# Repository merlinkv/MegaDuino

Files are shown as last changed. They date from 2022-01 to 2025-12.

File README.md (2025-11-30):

<br />This work is licensed under a <a rel="license" href="http://creativecommons.org/licenses/by-nc-sa/4.0/">Creative Commons Attribution-NonCommercial-ShareAlike 4.0 International License</a>.

* If you remix, transform, or build upon the material, you must distribute your contributions under the same license as the original.
* You may not use the material for commercial purposes.
* You must give appropriate credit, provide a link to the license, and indicate if changes were made. You may do so in any reasonable manner, but not in any way that suggests the licensor endorses you or your use.

# ATTENTION

   - This project was made for retro community, individuals or forums, and **NOT FOR COMMERCIAL PURPOSES**.
   - Its commercial sale on eBay, auction sites or shops (online or not) is PROHIBITED.
   - So only retro hardware forums and individual people with non profit intentions can build this project.

# Exception

  - If you wish to sell small quantities of this interface in a physical or online store, you must first contact me to request permission. The ban on selling it on eBay or auction sites remains in effect.

# Note

I take no responsibiltiy for any damage to any equipment that results from the use of this board.

USE AT YOUR OWN RISK!

# MegaDuino

An improved versión of the initial project started by me on September 2019.

MegaDuino is an evolution of other projects like TZXDuino and CASduino but it's based on the Arduino Mega 2560 Pro Embed board.

MegaDuino works with my **MegaDuino Firmware** version, a modification of the MaxDuino firmware specially developed for Arduino Mega 2560 family boards,
OLED 128x64 1.3" (64 rows) & LCD 20x4 screens, it also add an extra button for Reset or future purpouses. MaxDuino firmware from rcmolina can be used as well.

MegaDuino it's a digital cassette tape player that allows the load of games and applications on retro computers, mainly 8-bit computers such as the
ZX Spectrum, Amstrad CPC and others.

A special thanks to Alfredo (acf76es), without his help this update would not have been possible.

Original firmware based on developments by Andrew Beer, Duncan Edwards, rcmolina and others.

**MegaDuino** has been tested on **ZX Spectrum**, **Amstrad CPC**, **MSX**, **Oric Atmos**, **Dragon**, **Tandy Coco**, **Acorn Electron**, **BBC-Micro**, **ZX80** & **ZX81** computers.

# Board revisions and notes

* **30-11-2025 - MegaDuino 8.0**
  - Revised amplifier circuit
  - Some minor changes
  - [Interactive BOM MegaDuino 8.0](https://htmlpreview.github.io/?https://github.com/merlinkv/MegaDuino/blob/master/MegaDuino_8_0.html)

* **12-01-2025 - MegaDuino 5.5**
  - Added External Power Jack
  - Supressed Remote2 connector
  
* **12-08-2024 - MegaDuino 5.0 - Final**
  - Fixed some routing mistakes.
  - Board is fully working now

* **07-01-2024 - MegaDuino 5.0b (Beta - Not Tested)**
  - Although there are many versions of digital players for our retro equipments. It has encouraged me to do a new review of my **MegaDuino** project, with the idea of eliminating things that have proven to be unnecessary, giving it a much smaller format (note that it is not a mini or nano) and greater overall quality of the gadget.
  - Now the board use a mSD connector
  - Circuit of the mSD made with the help of @cacharreo (from VDR Forum), thanks my friend!
  - This Beta version is not tested at the moment. If you want to build one, use the v4.7.

* **01-01-2022 - MegaDuino 4.7**
  - In most cases is best to use the MegaDuino with the amplifier OFF.
  - Removed external power jack & led.
  - A 4-row piano switch was added to allow selection of remote and audio cable type (3.5mm jacks).
  - Added footprint to add one ICSP connector (optional) to allow use the Mega 2560 as master/slave board without opening the case.
  - Audio GAIN & FILTERS

* **05-10-2020 - MegaDuino PM 1.3**
  - All capacitors & resistors are SMD
  - Added Buzzer circuitry to allow listening the loading sounds directly from MegaDuino. Can be activated or deactivated.
  - Added 3mm leds for External Power, USB Power, Amplifier ON, Amplifier OFF & Buzzer ON/OFF
  - Amplifier & Buzzer gain can be selected (Amplifier 20, 50 & 200 - Buzzer 20 & 50) by jumpers
  - Two Remote connectors 2.5mm & 3.5mm to allow all connection possibilities
  - Removed ICSP pins

* **16-05-2020 - MegaDuino 2.9**
  - Reworked amplifier schema and added a DPDT slide switch to completely separate signal when the amplifier is ON or OFF.
  - Reworked connections of the Audio OUT jack to allow use of stereo or mono cables without need to modify them. Also eliminates undesired signals.
  - Removed extra 5v & 3.3v pins
  - ICSP pins moved to a better position to allow program the Mega 2560 or use master/slave boards without opening the case.

* **11-04-2020 - MegaDuino 2.8**
  - Jumpers added to allow selection of signal gain. Now it's possible to select between 50 and 200.

# Links:

* https://www.va-de-retro.com/foros/viewtopic.php?p=189490#p189490

# Images

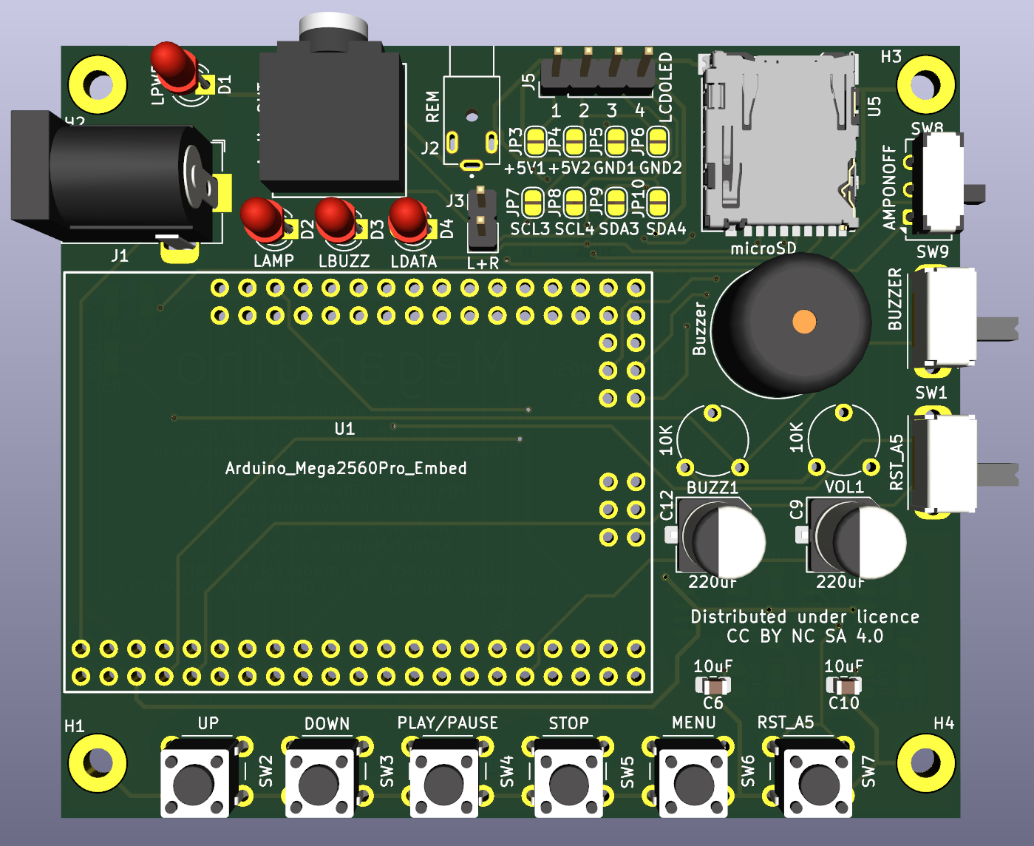
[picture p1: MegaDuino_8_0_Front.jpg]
Version 8.0 Front


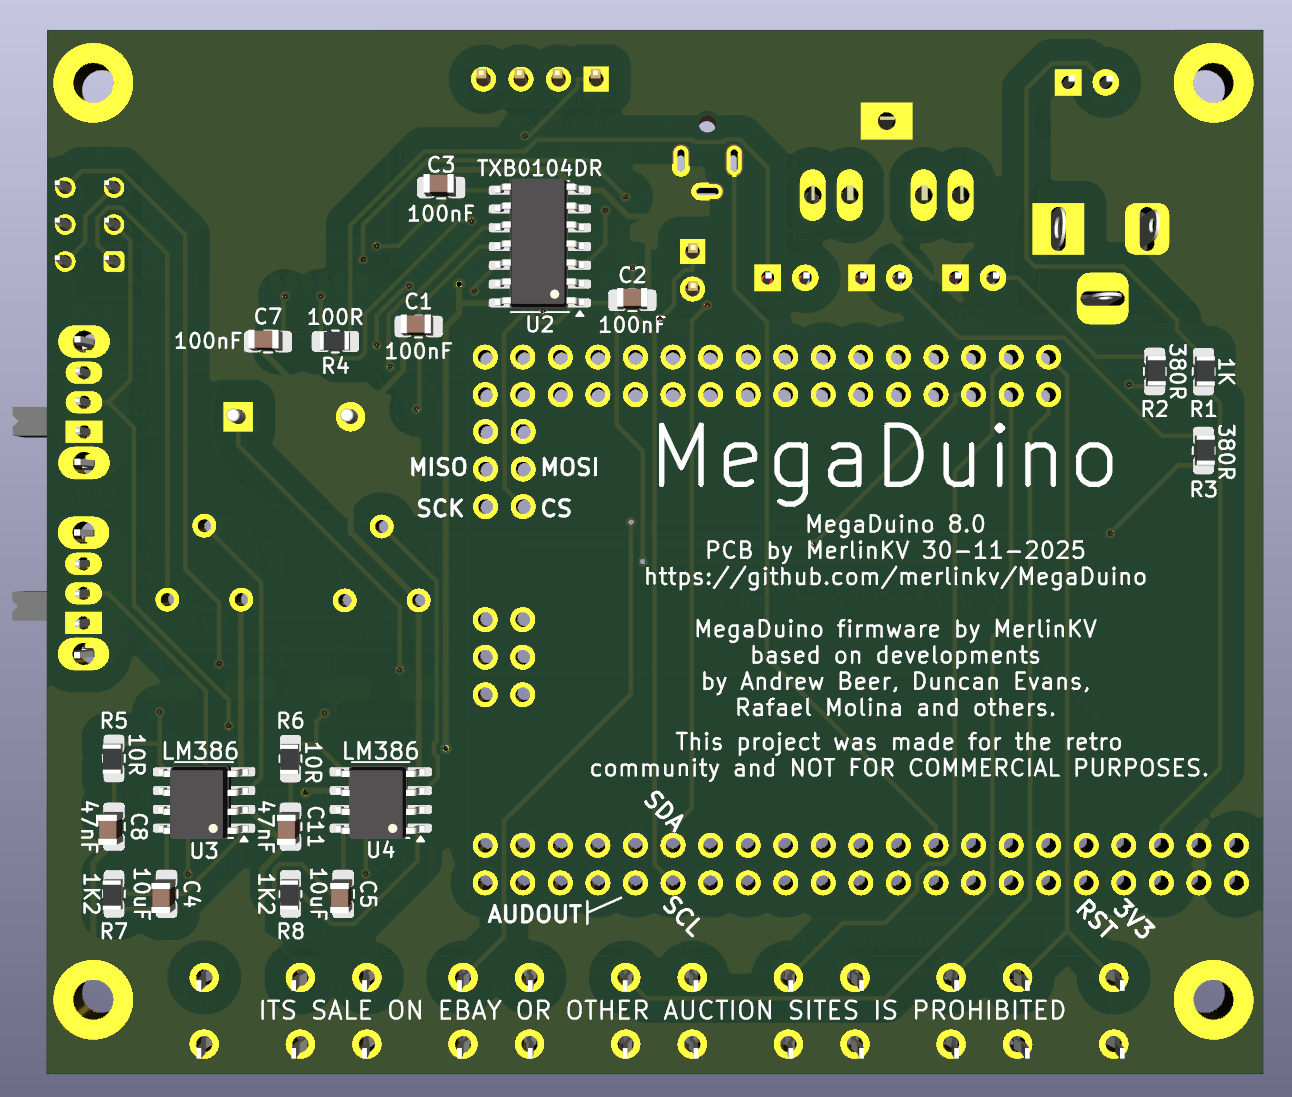
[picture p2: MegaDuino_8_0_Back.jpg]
Version 8.0 Back


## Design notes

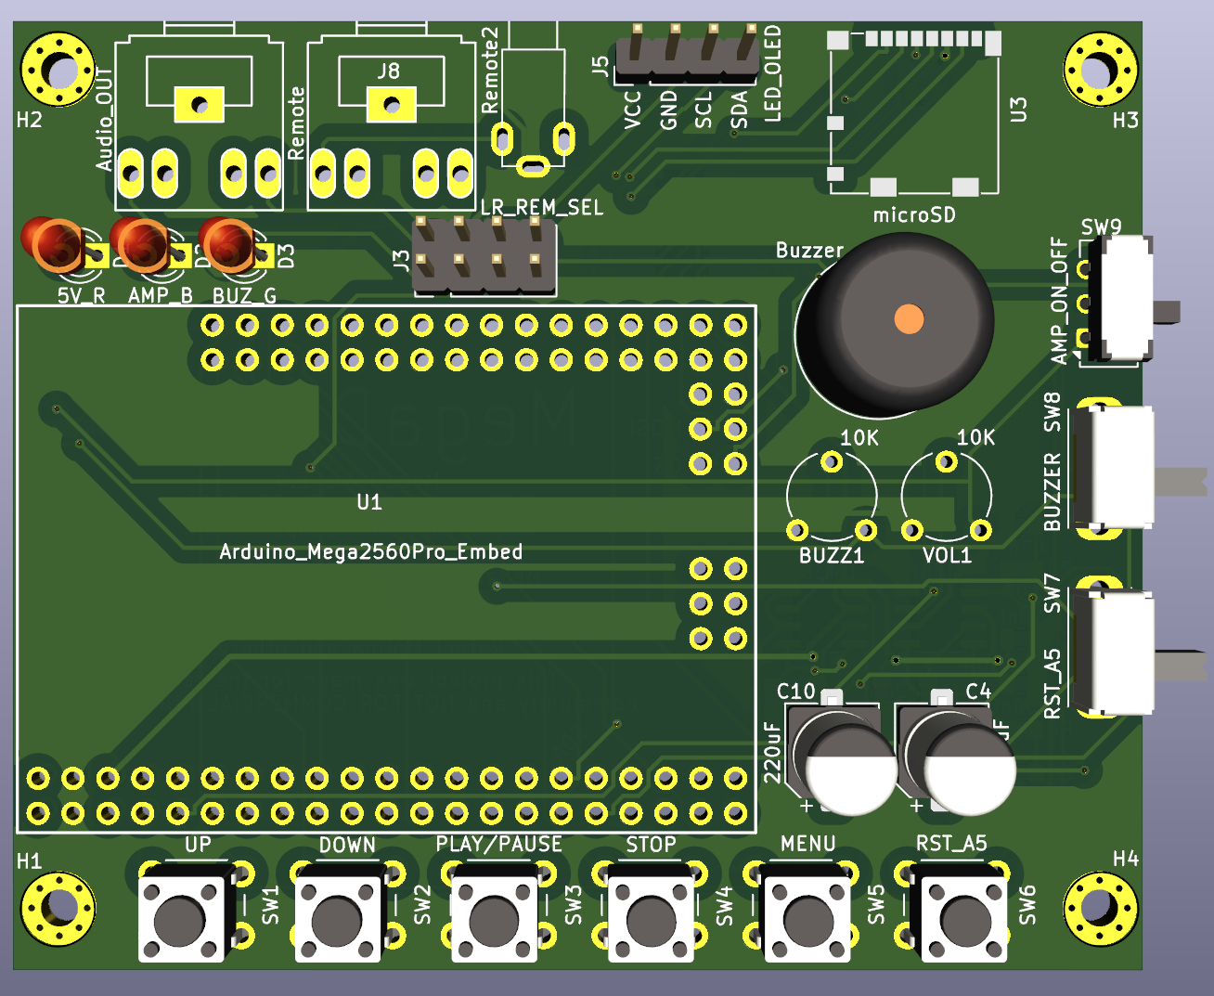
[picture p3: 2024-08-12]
MegaDuino_5/MegaDuino_5_Front.jpg

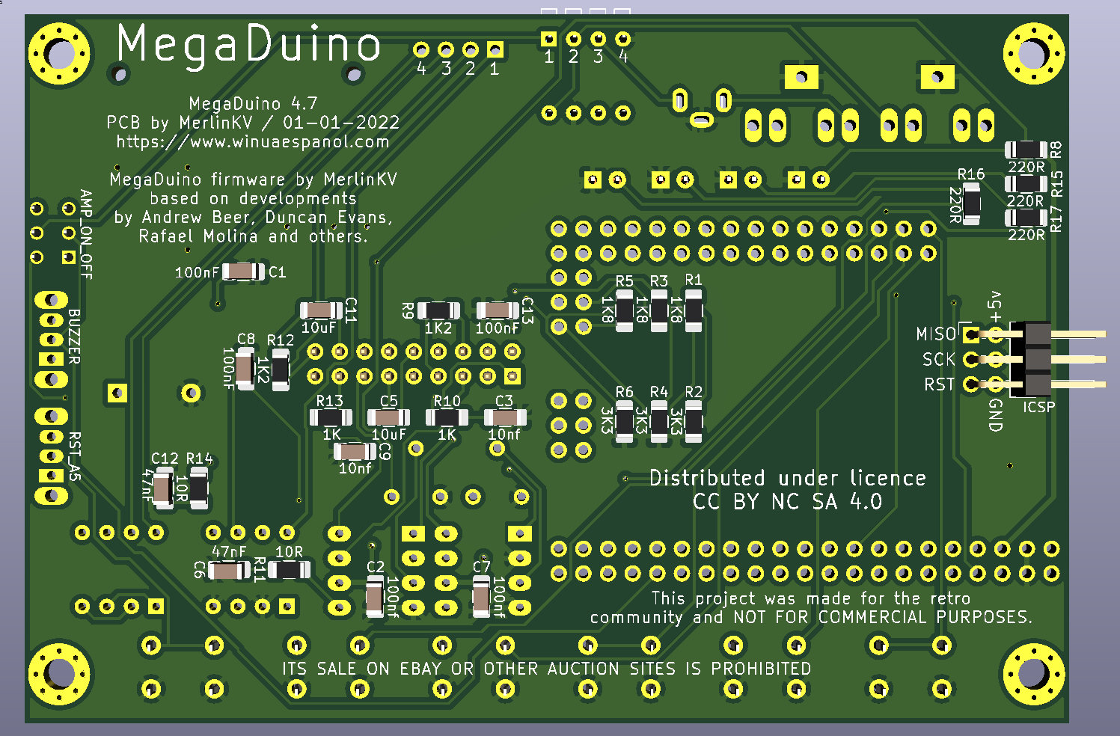
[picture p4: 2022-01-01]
MegaDuino_4_7/MegaDuino_4_7_Back.jpg

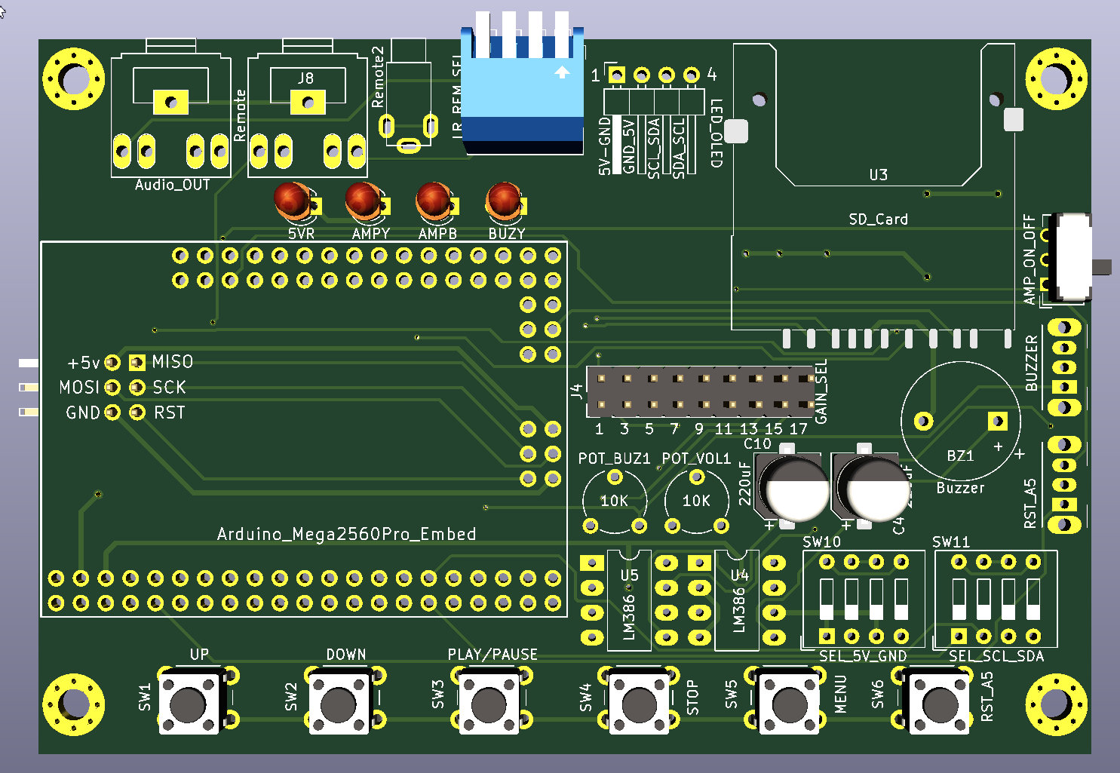
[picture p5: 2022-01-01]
MegaDuino_4_7/MegaDuino_4_7_Front.jpg

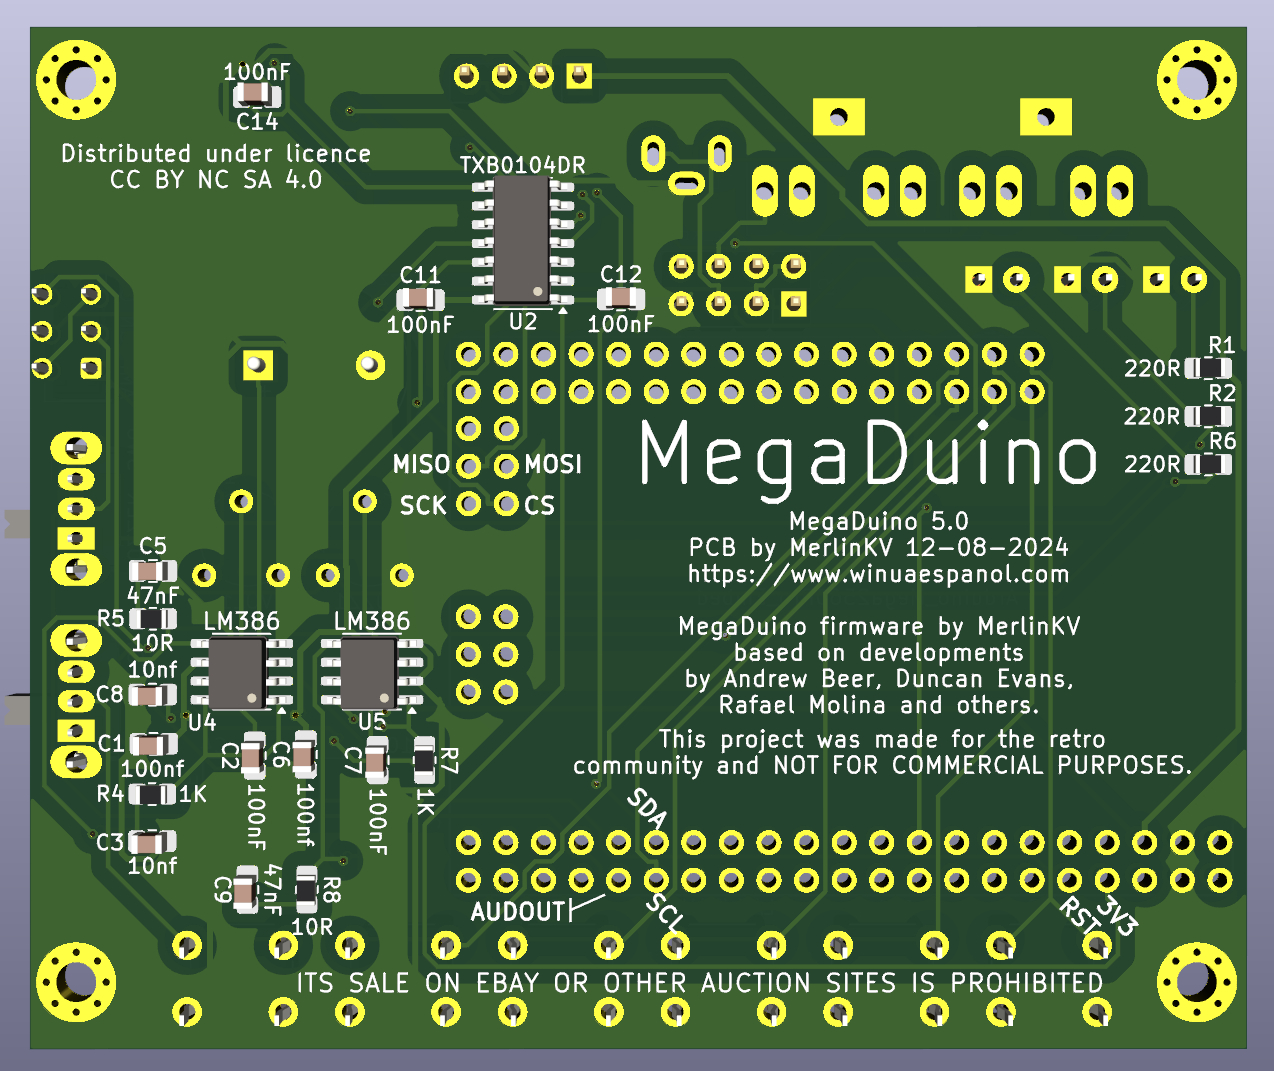
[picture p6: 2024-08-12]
MegaDuino_5/MegaDuino_5_Back.jpg

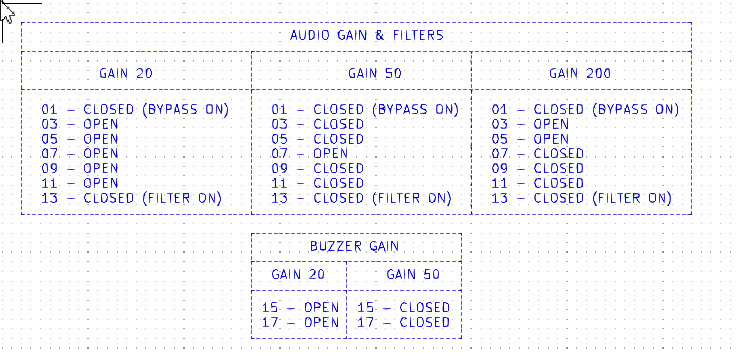
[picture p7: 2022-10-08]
MegaDuino_4_7/MegaDuino_4_7_Gain_Jumpers.jpg

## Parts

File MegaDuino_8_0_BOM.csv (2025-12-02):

Id | Designator | Footprint | Quantity | Designation | Supplier and ref
1 | R8,R7 | R_0805_2012Metric_Pad1.20x1.40mm_HandSolder | 2 | 1K2
2 | C10,C6,C5,C4 | C_0805_2012Metric_Pad1.18x1.45mm_HandSolder | 4 | 10uF
3 | C12,C9 | CP_Elec_6.3x7.7 | 2 | 220uF
4 | D1 | LED_D3.0mm | 1 | LPWR
5 | J4 | Audio Jack 3.5 PCB | 1 | Audio_OUT
6 | VOL1,BUZZ1 | Potentiometer_Piher_PT-6-V_Vertical | 2 | 10K
7 | SW2 | SW_PUSH_6mm | 1 | UP
8 | SW3 | SW_PUSH_6mm | 1 | DOWN
9 | SW4 | SW_PUSH_6mm | 1 | PLAY/PAUSE
10 | SW5 | SW_PUSH_6mm | 1 | STOP
11 | SW6 | SW_PUSH_6mm | 1 | MENU
12 | SW7 | SW_PUSH_6mm | 1 | RST_A5
13 | SW1 | SW_Slide_SPDT_Angled_CK_OS102011MA1Q | 1 | RST_A5
14 | BZ1 | Buzzer_12x9.5RM7.6 | 1 | Buzzer
15 | SW9 | SW_Slide_SPDT_Angled_CK_OS102011MA1Q | 1 | BUZZER
16 | SW8 | SW_CK_JS202011AQN_DPDT_Angled | 1 | AMPONOFF
17 | J5 | PinHeader_1x04_P2.54mm_Vertical | 1 | LCDOLED
18 | D2 | LED_D3.0mm | 1 | LAMP
19 | D3 | LED_D3.0mm | 1 | LBUZZ
20 | H1,H2,H3,H4 | MountingHole_2.7mm_M2.5_Pad | 4 | MHole
21 | U5 | microSD_HC_Hirose_DM3AT-SF-PEJM5 | 1 | microSD
22 | J1 | BarrelJack_Horizontal | 1 | DCDC_PWR
23 | J3 | SAMESKY_MJ1-2503A | 1 | REM
24 | D4 | LED_D3.0mm | 1 | LDATA
25 | J2 | PinHeader_1x02_P2.54mm_Vertical | 1 | L+R
26 | R1 | R_0805_2012Metric_Pad1.20x1.40mm_HandSolder | 1 | 1K
27 | U3,U4 | SOIC-8_3.9x4.9mm_P1.27mm | 2 | LM386
28 | C7,C1,C3,C2 | C_0805_2012Metric_Pad1.18x1.45mm_HandSolder | 4 | 100nF
29 | R2,R3 | R_0805_2012Metric_Pad1.20x1.40mm_HandSolder | 2 | 380R
30 | U2 | SOIC-14_3.9x8.7mm_P1.27mm | 1 | TXB0104DR
31 | R4 | R_0805_2012Metric_Pad1.20x1.40mm_HandSolder | 1 | 100R
32 | C11,C8 | C_0805_2012Metric_Pad1.18x1.45mm_HandSolder | 2 | 47nF
33 | R6,R5 | R_0805_2012Metric_Pad1.20x1.40mm_HandSolder | 2 | 10R
34 | U1 | Arduino_Mega2560Pro_Embed | 1 | Arduino_Mega2560Pro_Embed

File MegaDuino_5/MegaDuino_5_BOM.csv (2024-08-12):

Id | Designator | Footprint | Quantity | Designation | Supplier and ref
1 | C4,C10 | CP_Elec_6.3x7.7 | 2 | 220uF
2 | D1 | LED_D3.0mm | 1 | 5V_R
3 | J7 | Audio Jack 3.5 PCB | 1 | Audio_OUT
4 | VOL1,BUZZ1 | Potentiometer_Piher_PT-6-V_Vertical | 2 | 10K
5 | SW1 | SW_PUSH_6mm | 1 | UP
6 | SW2 | SW_PUSH_6mm | 1 | DOWN
7 | SW3 | SW_PUSH_6mm | 1 | PLAY/PAUSE
8 | SW4 | SW_PUSH_6mm | 1 | STOP
9 | SW5 | SW_PUSH_6mm | 1 | MENU
10 | SW6 | SW_PUSH_6mm | 1 | RST_A5
11 | SW7 | SW_Slide_SPDT_Angled_CK_OS102011MA1Q | 1 | RST_A5
12 | BZ1 | Buzzer_12x9.5RM7.6 | 1 | Buzzer
13 | SW8 | SW_Slide_SPDT_Angled_CK_OS102011MA1Q | 1 | BUZZER
14 | SW9 | SW_CK_JS202011AQN_DPDT_Angled | 1 | AMP_ON_OFF
15 | J5 | PinHeader_1x04_P2.54mm_Vertical | 1 | LED_OLED
16 | J8 | Audio Jack 3.5 PCB | 1 | Remote
17 | D2 | LED_D3.0mm | 1 | AMP_B
18 | D3 | LED_D3.0mm | 1 | BUZ_G
19 | J2 | Jack_2.5mm_Mono_Horizontal_Mini | 1 | Remote2
20 | U1 | Arduino_Mega2560Pro_Embed | 1 | Arduino_Mega2560Pro_Embed
21 | H1,H2,H3,H4 | MountingHole_2.7mm_M2.5_Pad_Via | 4 | MHole
22 | J3 | PinHeader_2x04_P2.54mm_Vertical | 1 | LR_REM_SEL
23 | U3 | microSD_HC_Molex_104031-0811 | 1 | microSD
24 | C5,C9 | C_0805_2012Metric_Pad1.18x1.45mm_HandSolder | 2 | 47nF
25 | C3,C8 | C_0805_2012Metric_Pad1.18x1.45mm_HandSolder | 2 | 10nf
26 | C2,C7,C11,C12,C14 | C_0805_2012Metric_Pad1.18x1.45mm_HandSolder | 5 | 100nF
27 | R1,R2,R6 | R_0805_2012Metric_Pad1.20x1.40mm_HandSolder | 3 | 220R
28 | R4,R7 | R_0805_2012Metric_Pad1.20x1.40mm_HandSolder | 2 | 1K
29 | R5,R8 | R_0805_2012Metric_Pad1.20x1.40mm_HandSolder | 2 | 10R
30 | U4,U5 | SOIC-8_3.9x4.9mm_P1.27mm | 2 | LM386
31 | C6,C1 | C_0805_2012Metric_Pad1.18x1.45mm_HandSolder | 2 | 100nf
32 | U2 | SOIC-14_3.9x8.7mm_P1.27mm | 1 | TXB0104DR

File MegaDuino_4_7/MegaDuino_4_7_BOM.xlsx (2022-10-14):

Id | Designator | Package | Quantity | Designation | Supplier and ref
1 | SW7 | SW_CuK_OS102011MA1QN1_SPDT_Angled | 1 | RST_A5
2 | SW8 | SW_CuK_OS102011MA1QN1_SPDT_Angled | 1 | BUZZER
3 | U1 | Arduino_Mega2560Pro_Embed | 1 | Arduino_Mega2560Pro_Embed
4 | J6 | PinHeader_2x03_P2.54mm_Horizontal | 1 | ICSP
5 | SW12 | SW_DIP_SPSTx04_Piano_10.8x11.72mm_W7.62mm_P2.54mm | 1 | LR_REM_SEL
6 | U3 | SD_Card | 1 | SD_Card | ie: https://www.ebay.es/itm/152757963262
7 | R11,R14 | R_1206_3216Metric_Pad1.42x1.75mm_HandSolder | 2 | 10R
8 | C8,C13,C1 | C_1206_3216Metric_Pad1.42x1.75mm_HandSolder | 3 | 100nF
9 | R17,R16,R15,R8 | R_1206_3216Metric_Pad1.42x1.75mm_HandSolder | 4 | 220R
10 | R13,R10 | R_1206_3216Metric_Pad1.42x1.75mm_HandSolder | 2 | 1K
11 | R12,R9 | R_1206_3216Metric_Pad1.42x1.75mm_HandSolder | 2 | 1K2
12 | R6,R4,R2 | R_1206_3216Metric_Pad1.42x1.75mm_HandSolder | 3 | 3K3
13 | R5,R3,R1 | R_1206_3216Metric_Pad1.42x1.75mm_HandSolder | 3 | 1K8
14 | C12,C6 | C_1206_3216Metric_Pad1.42x1.75mm_HandSolder | 2 | 47nF
15 | C11,C5 | C_1206_3216Metric_Pad1.42x1.75mm_HandSolder | 2 | 10uF
16 | C9,C3 | C_1206_3216Metric_Pad1.42x1.75mm_HandSolder | 2 | 10nf
17 | C7,C2 | C_1206_3216Metric_Pad1.42x1.75mm_HandSolder | 2 | 100nf
18 | D4 | LED_D3.0mm | 1 | AMPB
19 | SW1 | SW_PUSH_6mm | 1 | UP
20 | SW9 | SW_CuK_JS202011AQN_DPDT_Angled | 1 | AMP_ON_OFF
21 | SW6 | SW_PUSH_6mm | 1 | RST_A5
22 | SW5 | SW_PUSH_6mm | 1 | MENU
23 | SW4 | SW_PUSH_6mm | 1 | STOP
24 | SW3 | SW_PUSH_6mm | 1 | PLAY/PAUSE
25 | SW2 | SW_PUSH_6mm | 1 | DOWN
26 | J2 | Jack_2.5mm_Mono_Horizontal_Mini | 1 | Remote2
27 | D5 | LED_D3.0mm | 1 | BUZY
28 | D3 | LED_D3.0mm | 1 | AMPY
29 | J4 | PinHeader_2x09_P2.54mm_Vertical | 1 | GAIN_SEL
30 | J8 | Audio Jack 3.5 PCB | 1 | Remote
31 | J5 | PinHeader_1x04_P2.54mm_Horizontal_2 | 1 | LED_OLED
32 | J7 | Audio Jack 3.5 PCB | 1 | Audio_OUT
33 | SW11 | SW_DIP_SPSTx04_Slide_9.78x12.34mm_W7.62mm_P2.54mm | 1 | SEL_SCL_SDA
34 | C10,C4 | CP_Elec_6.3x7.7 | 2 | 220uF
35 | U5,U4 | DIP-8_W7.62mm_LongPads | 2 | LM386
36 | POT_BUZ1,POT_VOL1 | Potentiometer_Piher_PT-6-V_Vertical | 2 | 10K
37 | BZ1 | Buzzer_12x9.5RM7.6 | 1 | Buzzer
38 | HOLE2,HOLE1,HOLE3,HOLE4 | MountingHole_3.2mm_M3_Pad_Via | 4 | MountingHole_3.2mm_M3_Pad_Via
39 | SW10 | SW_DIP_SPSTx04_Slide_9.78x12.34mm_W7.62mm_P2.54mm | 1 | SEL_5V_GND
40 | D2 | LED_D3.0mm | 1 | 5VR

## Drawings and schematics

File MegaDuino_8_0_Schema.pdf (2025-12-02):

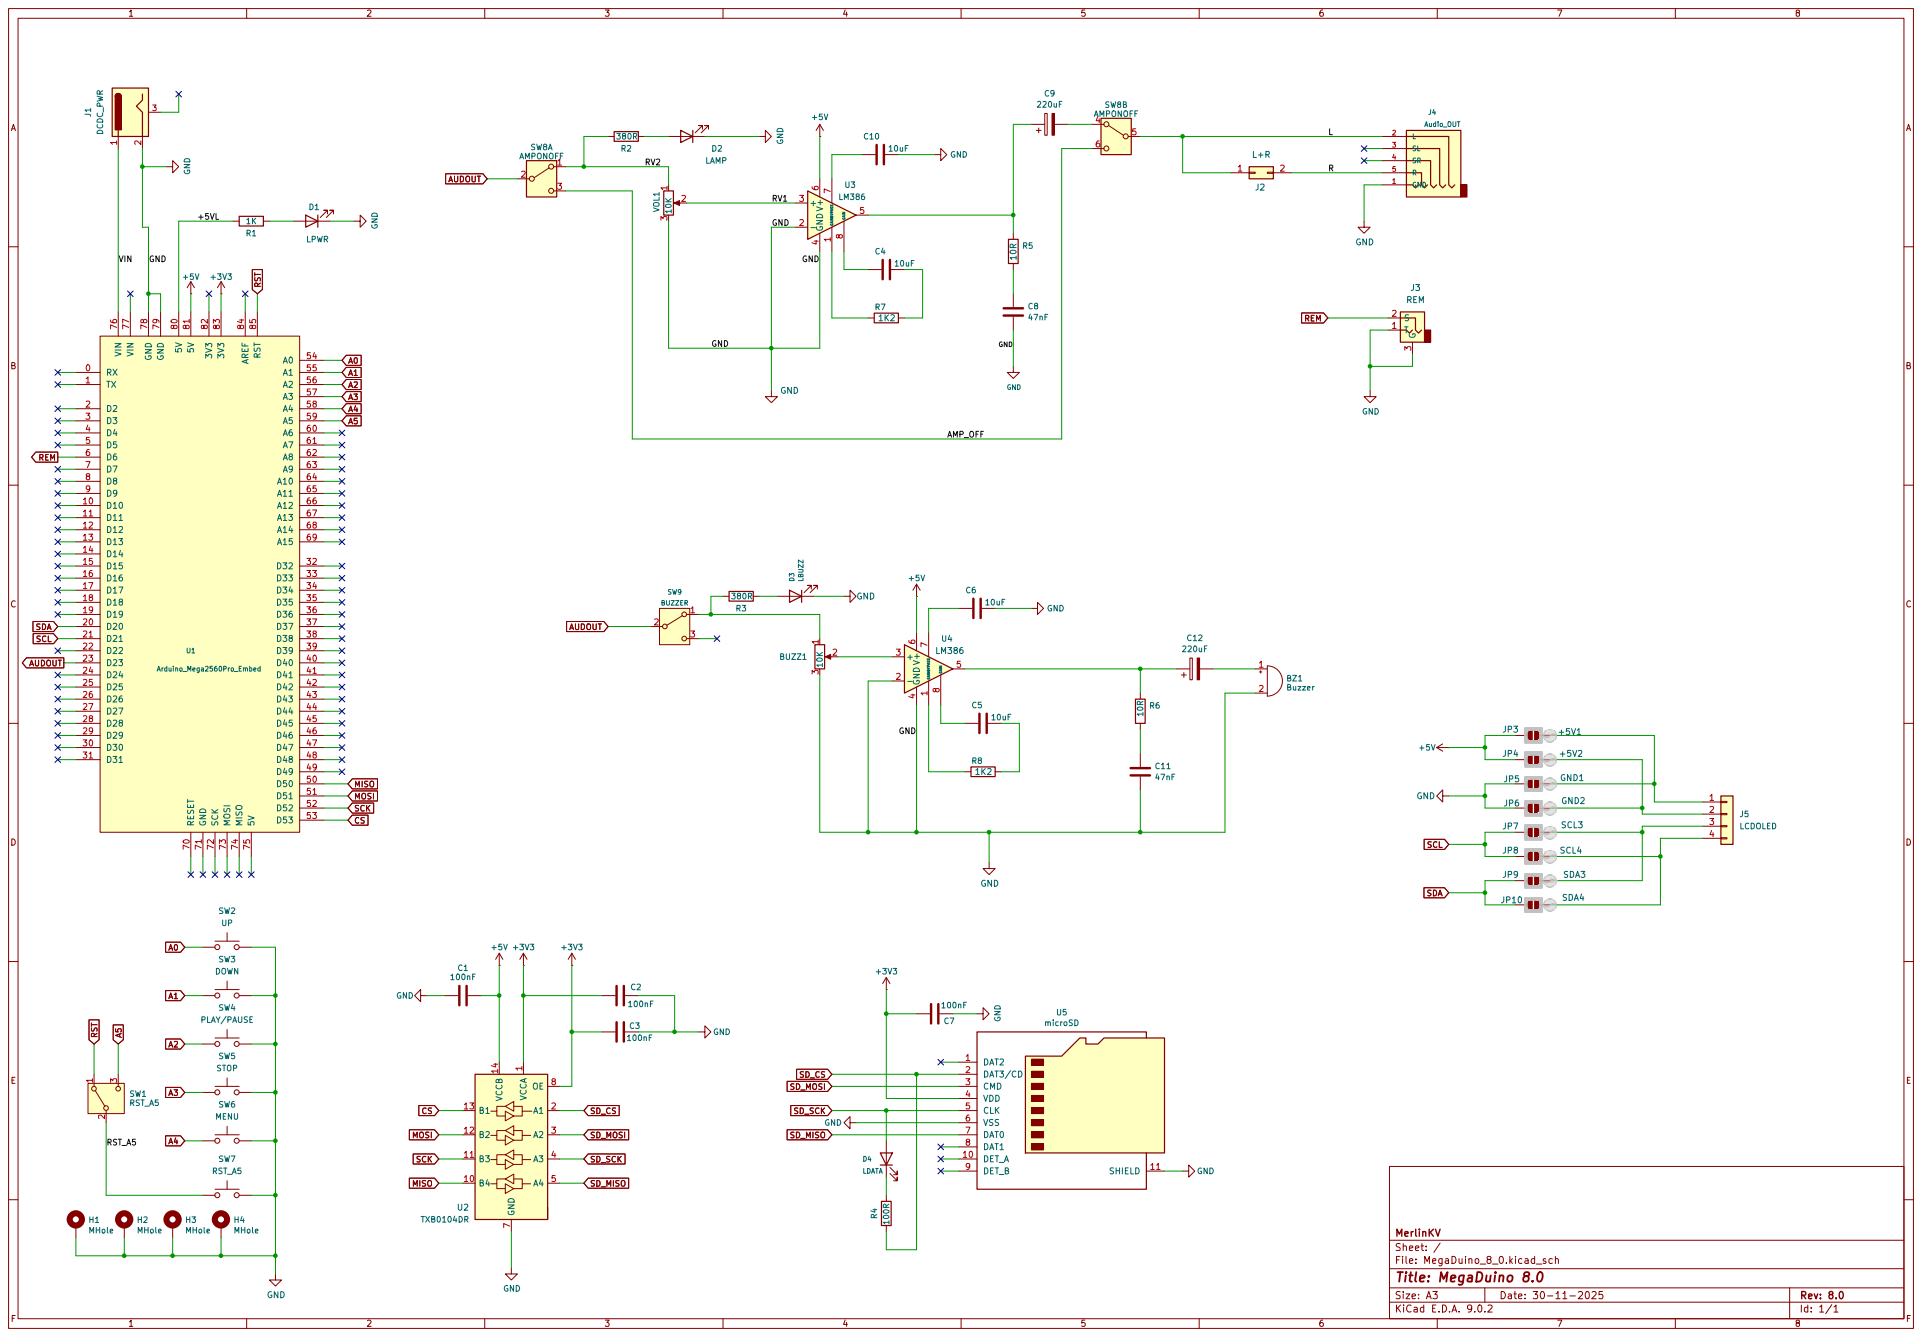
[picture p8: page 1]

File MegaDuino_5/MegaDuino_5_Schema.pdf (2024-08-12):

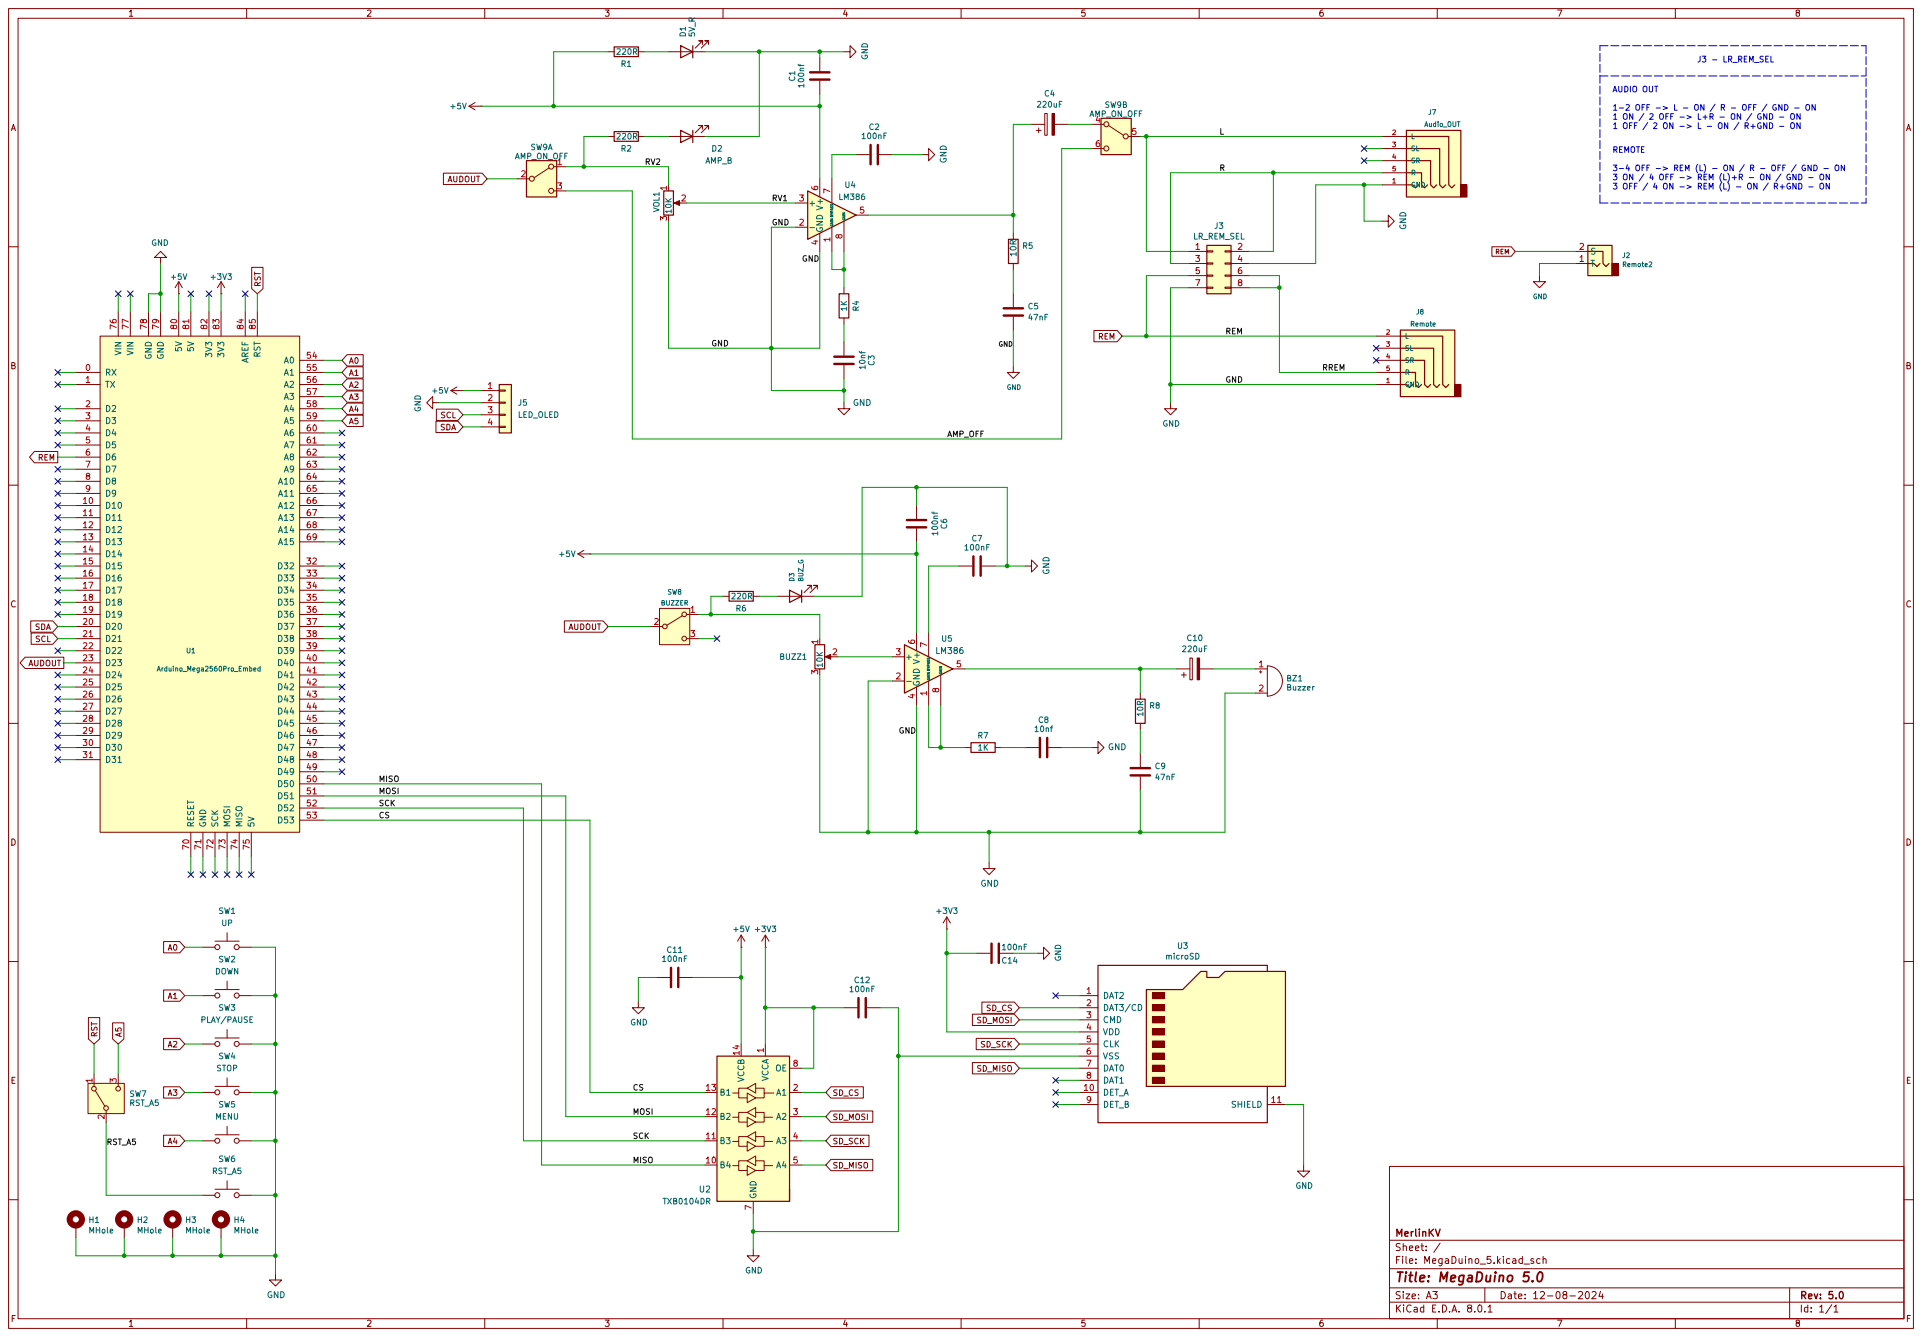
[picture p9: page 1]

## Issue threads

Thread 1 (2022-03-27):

duvida

darleiv, 2022-03-27:
qual a ultilidade deste megaduino/;

mjcargill, 2022-05-20:
HI,

is there a schematic that I can open in Kicad or similar to get a BOM and parts placement to get this made?

merlinkv, 2022-10-13:
Hi,

The BOM is inside the Gerbers zip file, is a file named: **MegaDuino_4_7.csv** and can be opened with Excel or LibreCalc.
